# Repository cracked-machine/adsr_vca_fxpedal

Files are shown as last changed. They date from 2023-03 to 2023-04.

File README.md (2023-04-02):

# adsr_vca_fxpedal
MCU generated ADSR envelope into a LM13700 OTA VCA

## Block diagram

The audio input signal is amplitude-modulated with the ADSR waveform using the [LM13700](docs/datasheet/lm13700.pdf) in a voltage controlled amplifier (VCA) confguration.

ADSR waveform is generated via software running on a [microcontroller](docs/datasheet/stm32l432kb_datasheet.pdf) with built-in dual DAC. Two ADSR signals are generated: Inverted and Non-inverted.

ADSR generation is triggered by detecting the peak of the input signal or by manual push button. The latter can be used as a manual retrigger mechanism.

ADSR values - attack, decay, sustain and release - can be selected and then adjusted using the four potentiometers.  

An OLED display will show the current ADSR envelope shape as it is adjusted.

The raw ADSR envelope signal and VCA output are available as buffered output on 2.54mm connectors.



Both the inverted and non-inverted ADSR-modulated signals are mixed with the original "clean" audio input signal in the output stage. The mix of all three signals can be independently adjusted.

## Power Supply Scheme

This supports both guitar applications (9VDC) and modular synth (+/-12V) by switching the jumpers.

Note the 9VDC rail is split to +/-4.5VDC.



Implementation can be seen on the schematic page



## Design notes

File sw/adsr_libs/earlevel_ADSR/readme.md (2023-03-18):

https://www.earlevel.com/main/2013/06/03/envelope-generators-adsr-code/

### Compile

```
g++ -std=c++17 *.cpp -o adsr
```

### run

```
./adsr
```

### Example output

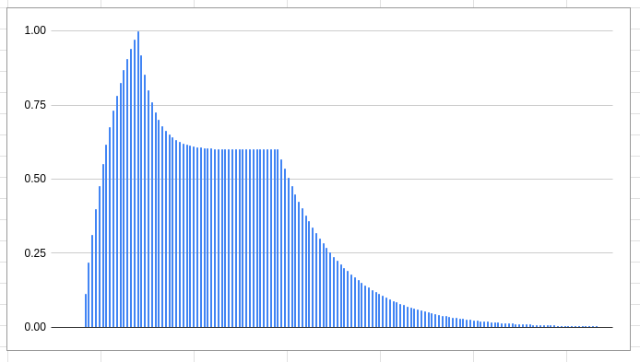
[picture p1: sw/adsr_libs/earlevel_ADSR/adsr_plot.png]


parameters:

```
sampleRate = 80
AttackRate = 0.1s
DecayRate = 0.25s
ReleaseRate = 1s
SustainLevel = 0.6
gate duration = 100ms
```

Raw data can be found in [data.txt](data.txt)

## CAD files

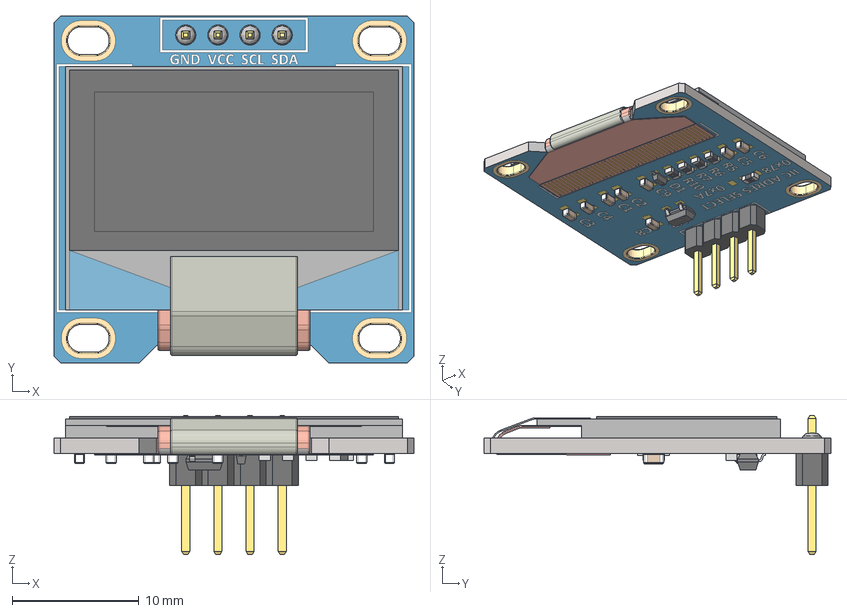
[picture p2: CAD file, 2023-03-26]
hw/3dmodels/Pantalla OLED 0.96'' 128x64.stp
28.4 x 27.4 x 11.0 mm
SOT-23_TOR
RES_CR16_MTK_1 x 4
RES_CR16_MTK
SOD323F_DIO

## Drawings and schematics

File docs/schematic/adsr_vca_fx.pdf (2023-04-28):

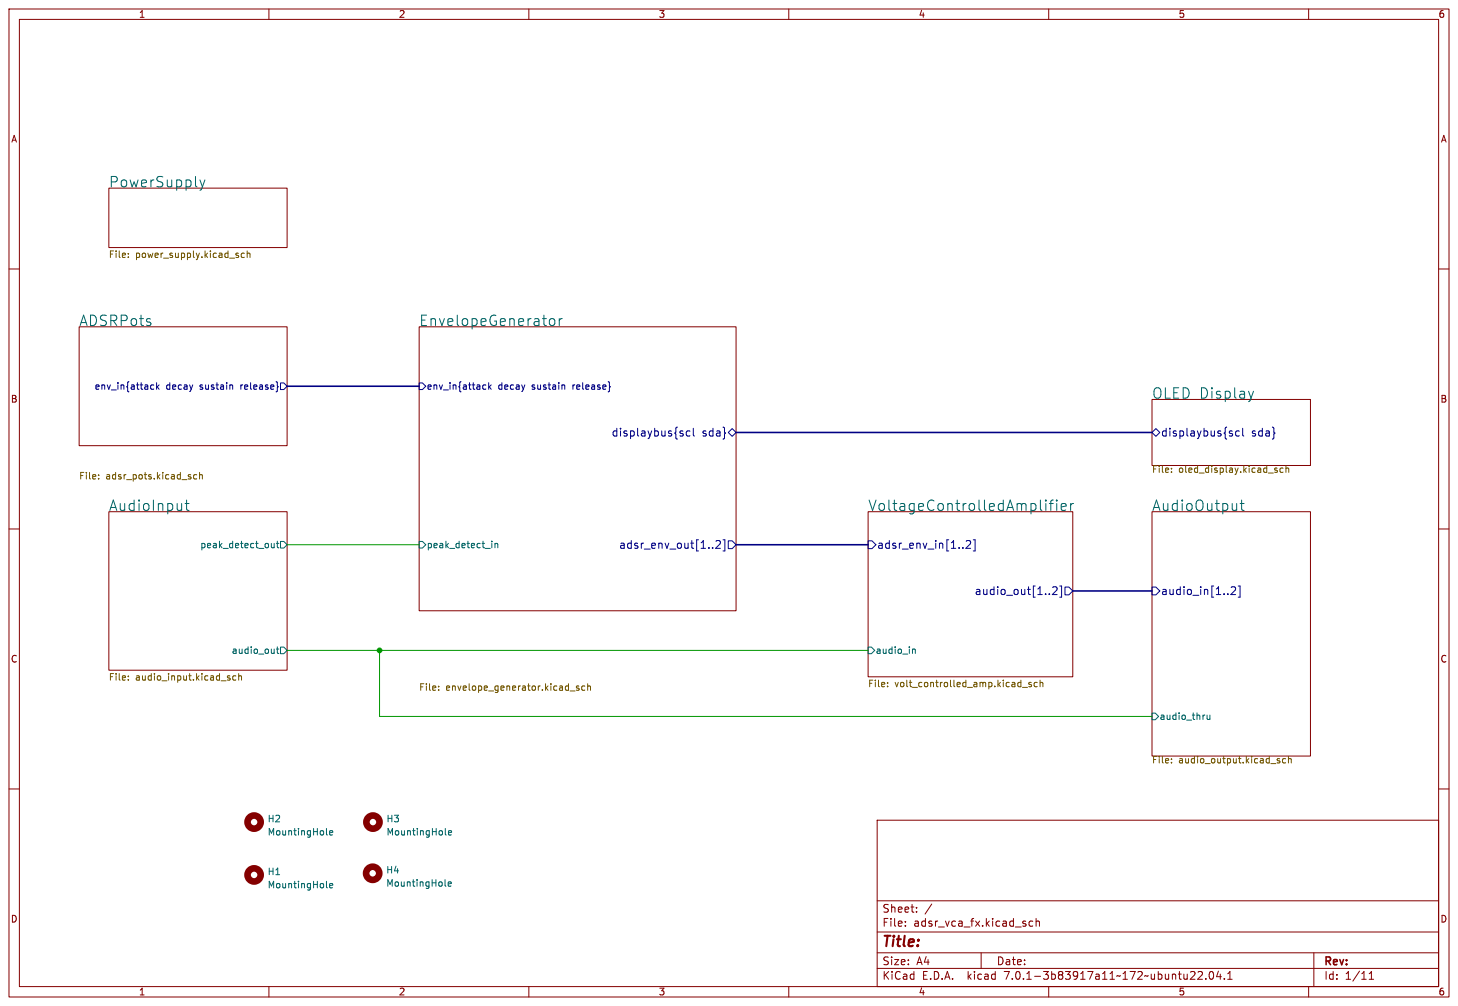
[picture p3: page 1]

EnvelopeGenerator File: envelope_generator.kicad_sch H3 MountingHole H4 MountingHole H1 MountingHole H2 MountingHole

Id: 1/11 Title: File: adsr_vca_fx.kicad_sch Sheet: /

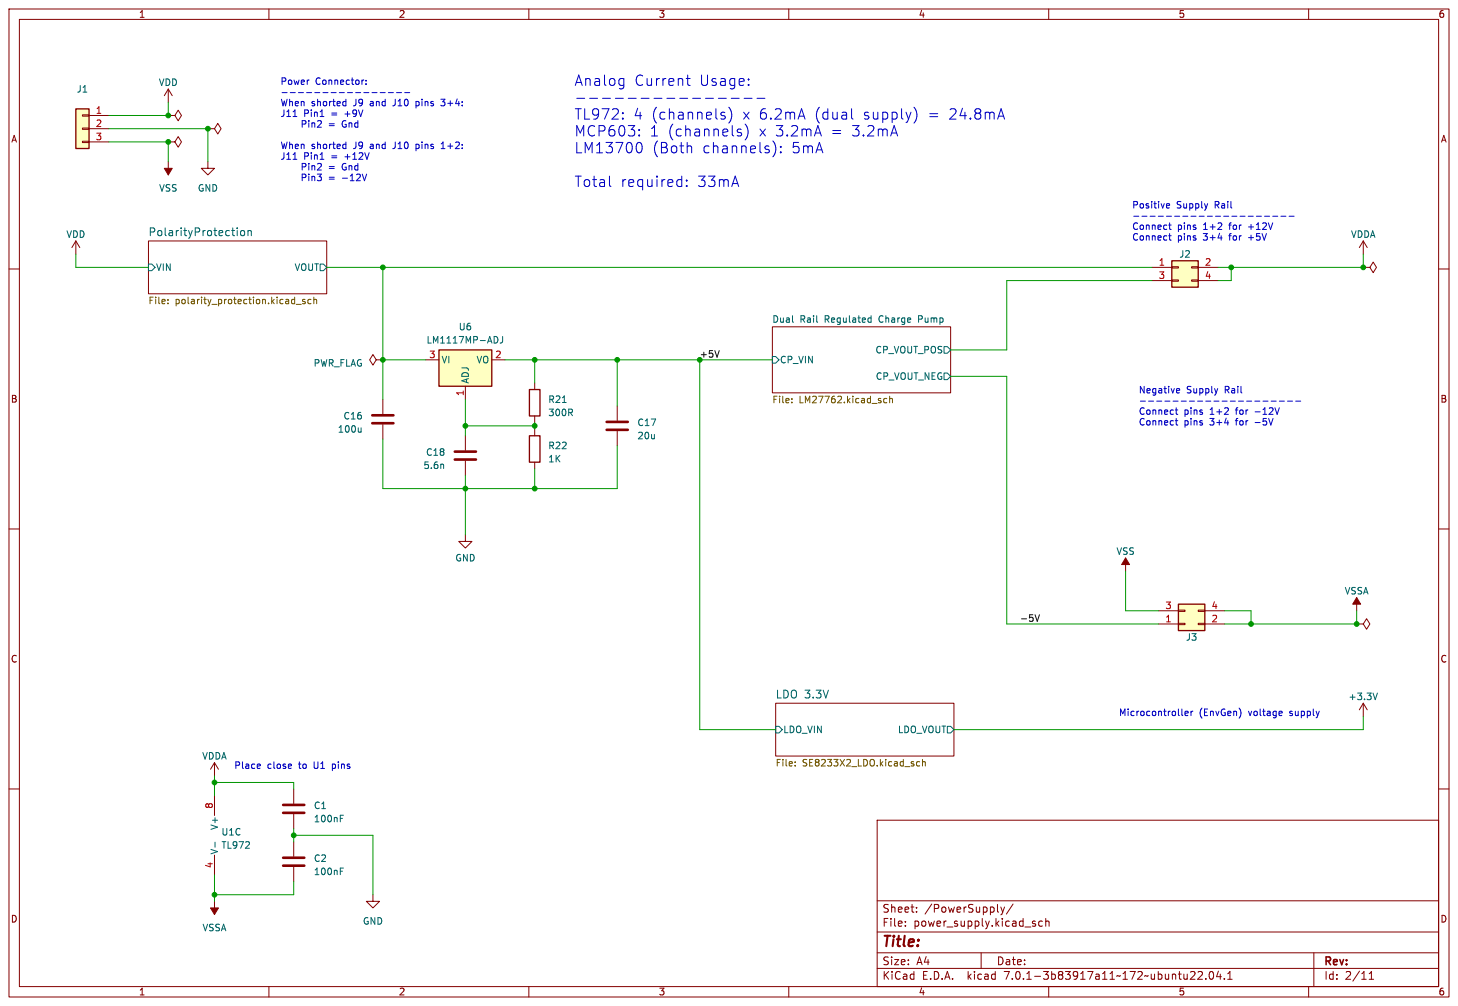
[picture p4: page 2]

Power Connector: ---------------- When shorted J9 and J10 pins 3+4: J11 Pin1 = +9V

Pin2 = Gnd When shorted J9 and J10 pins 1+2: J11 Pin1 = +12V

Dual Rail Regulated Charge Pump File: LM27762.kicad_sch

Negative Supply Rail -------------------- Connect pins 1+2 for -12V Connect pins 3+4 for -5V

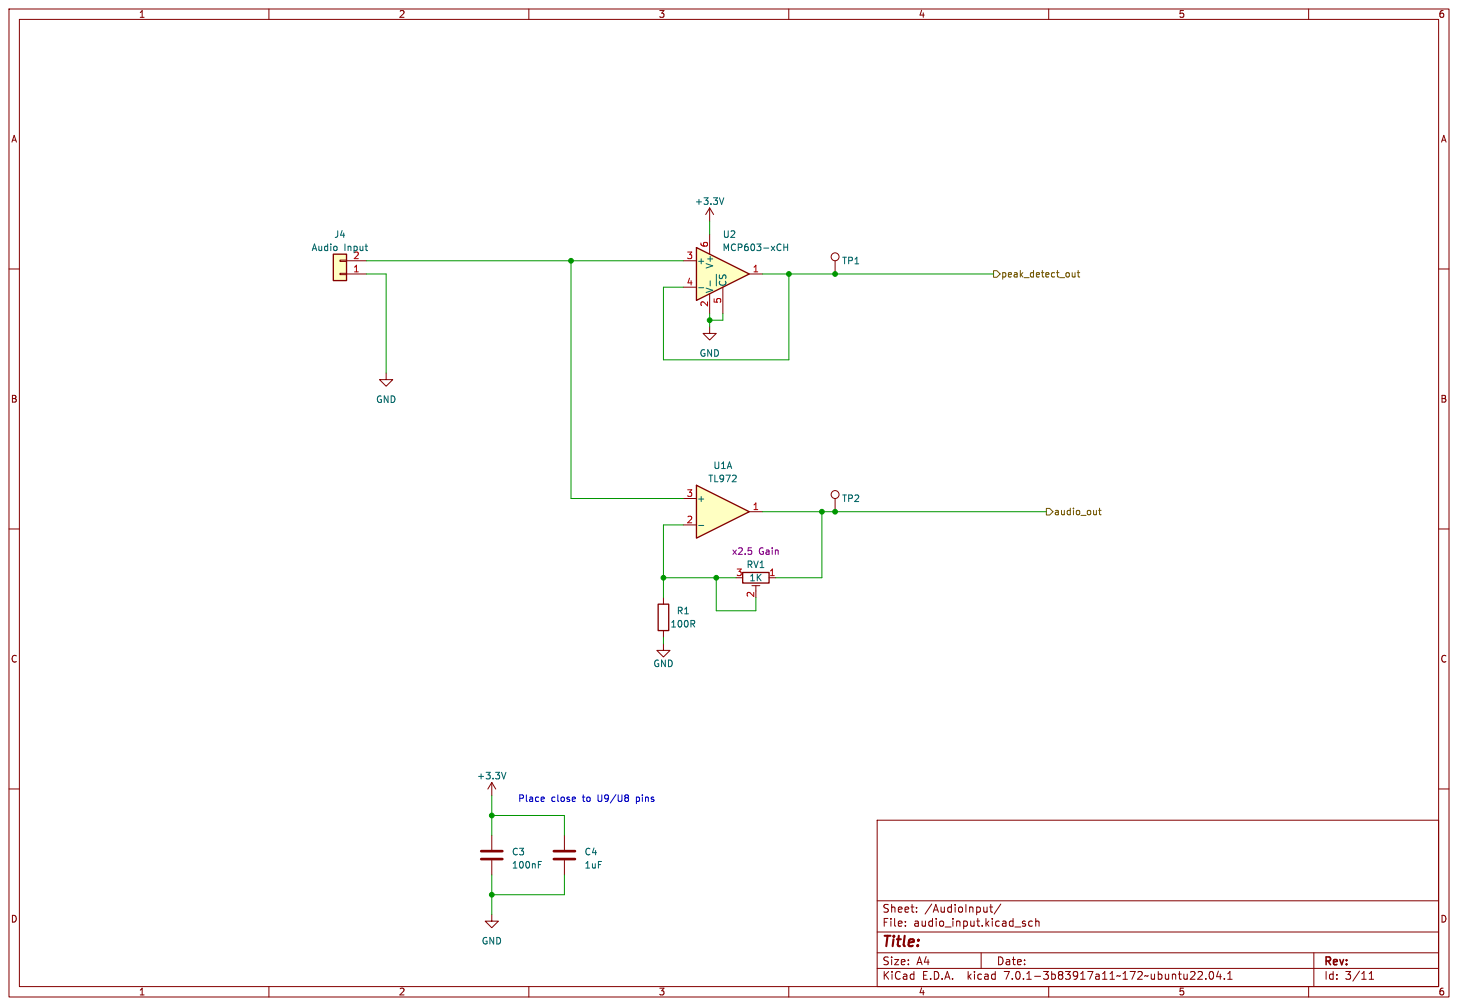
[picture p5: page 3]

Id: 3/11 Title: File: audio_input.kicad_sch Sheet: /AudioInput/ C4

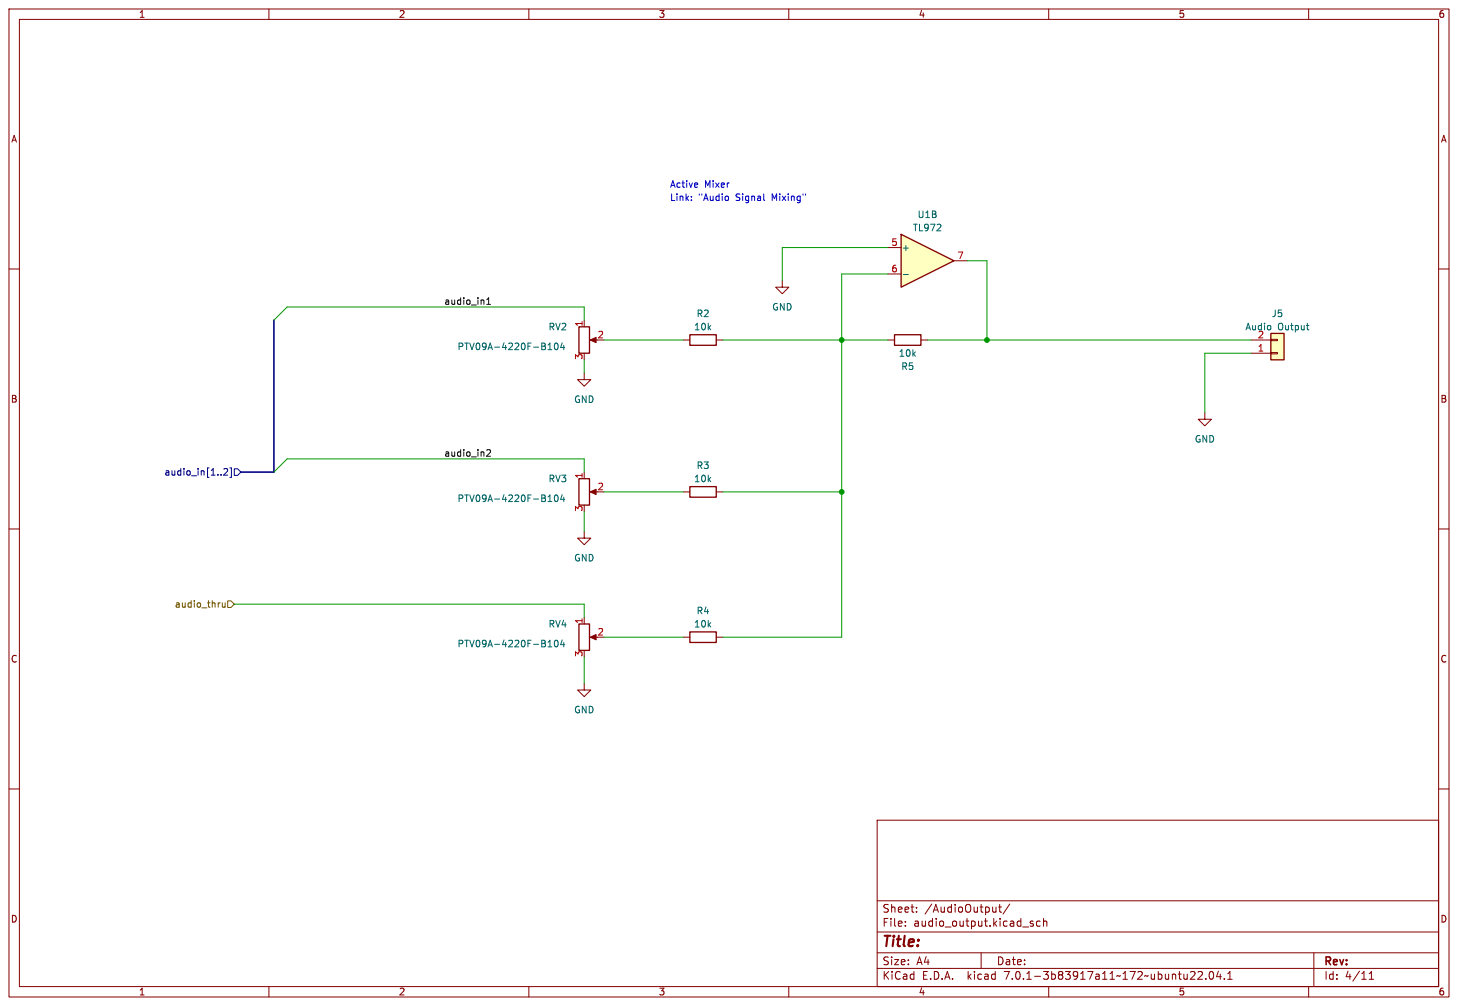
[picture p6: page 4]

Link: "Audio Signal Mixing" (https://sound-au.com/articles/audio-mixing.htm#s3) Active Mixer

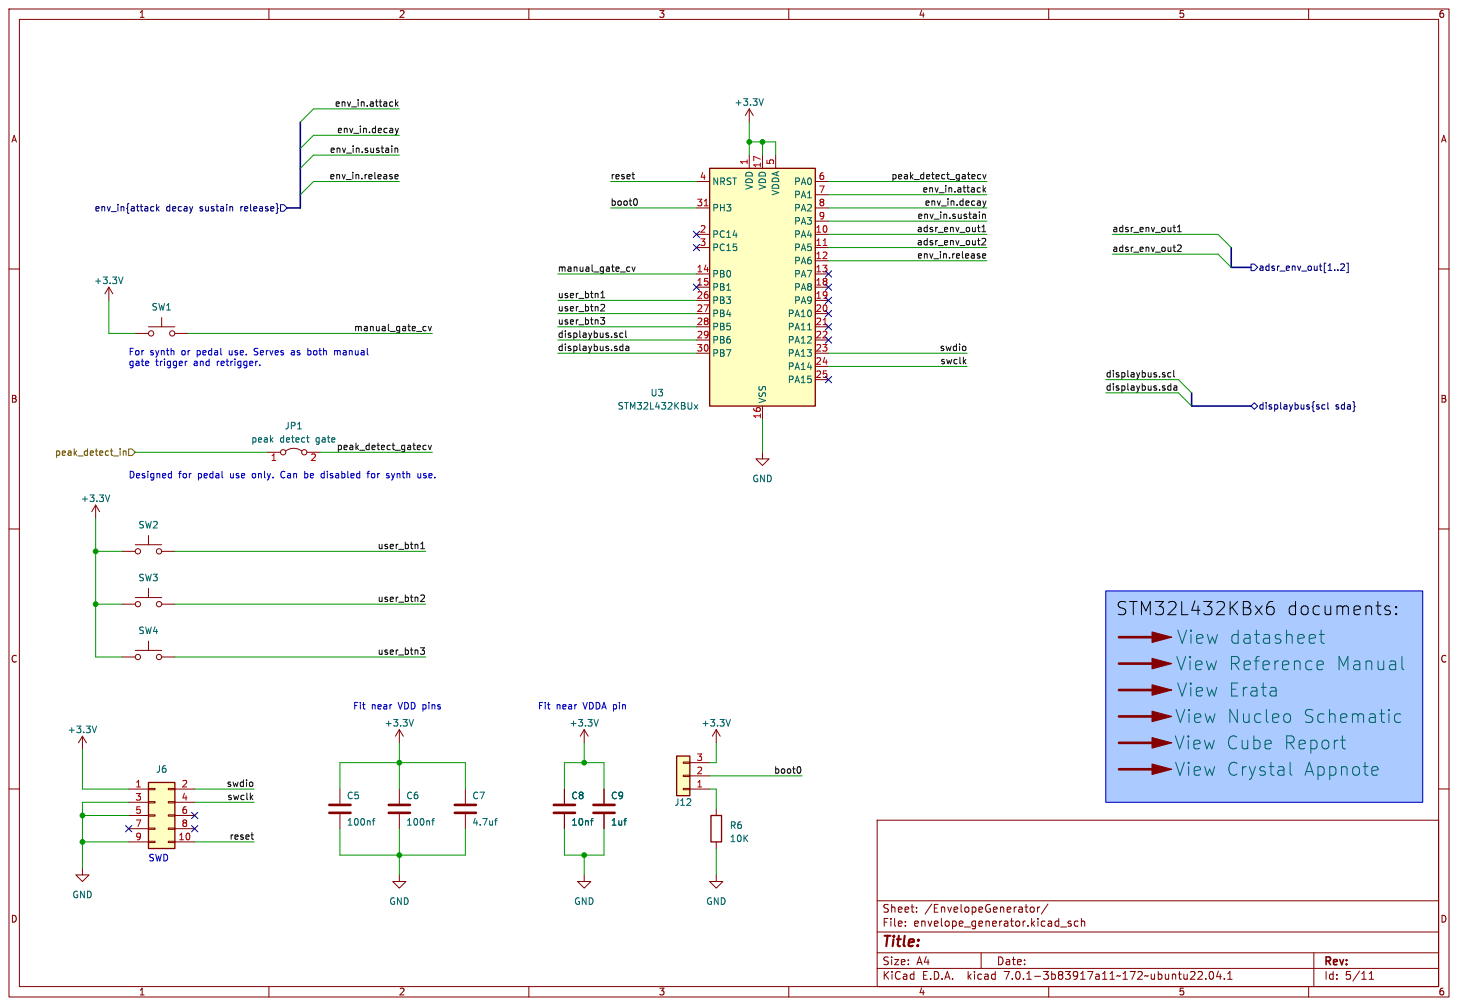
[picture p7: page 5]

1 PA4 10 PA5 11 PA6 12 PA7 13 PB0 14 PB1 15 VSS 16 VDD 17 PA8 18 PA9 19 PC14 2 PA10 20 PA11 21 PA12 22 PA13 23 PA14 24 PA15 25 PB3 26 PB4 27 PB5 28 PB6 29 PC15 3 PB7 30 PH3 31 NRST 4 VDDA

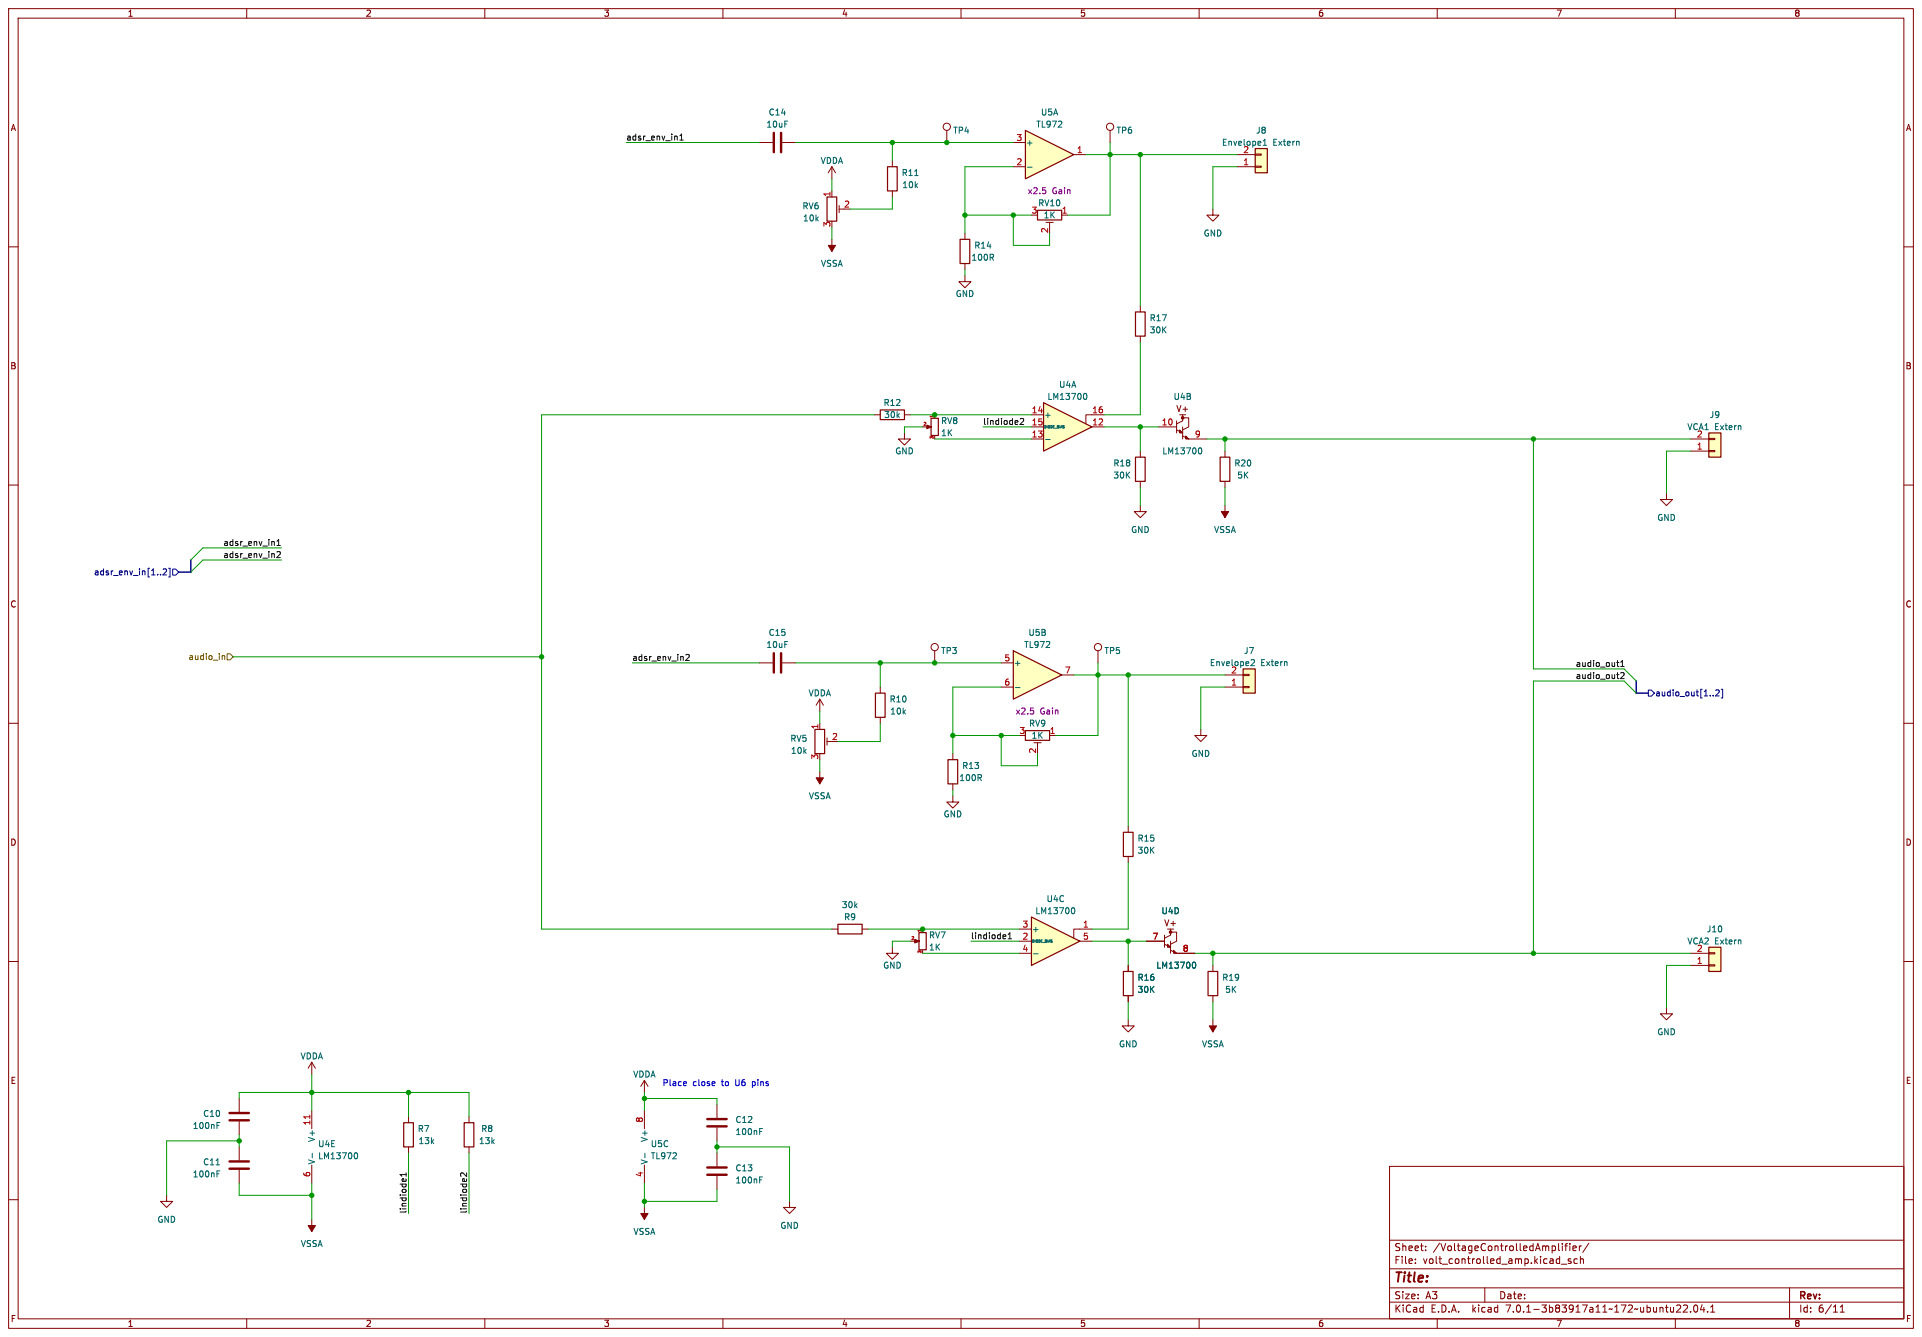
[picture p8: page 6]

Id: 6/11 Title: File: volt_controlled_amp.kicad_sch Sheet: /VoltageControlledAmplifier/

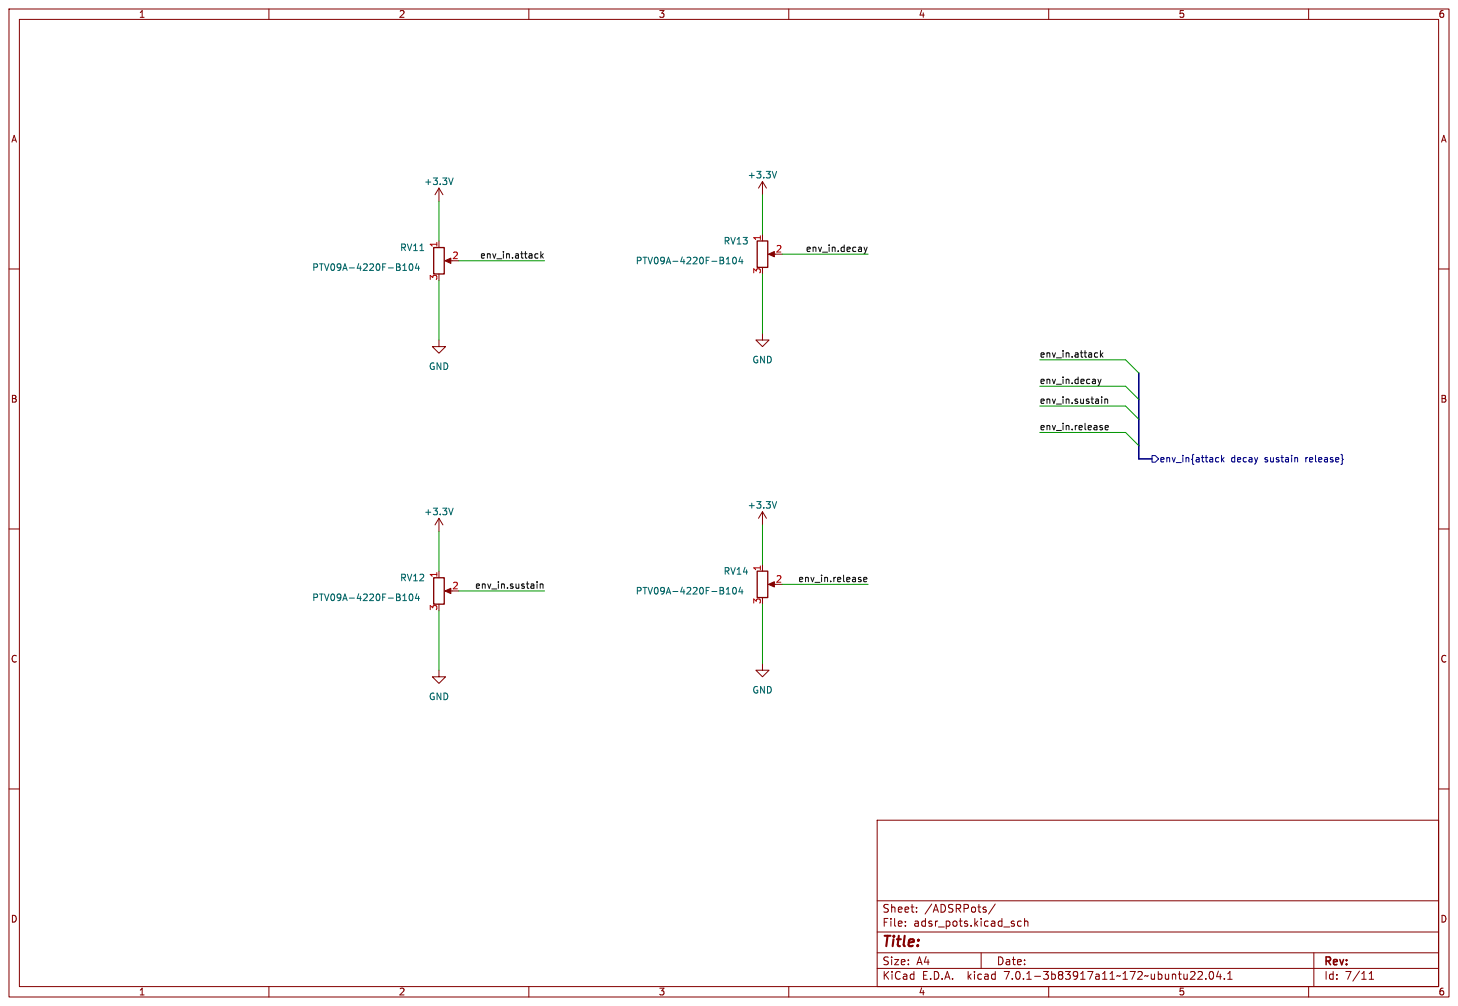
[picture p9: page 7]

Id: 7/11 Title: File: adsr_pots.kicad_sch Sheet: /ADSRPots/

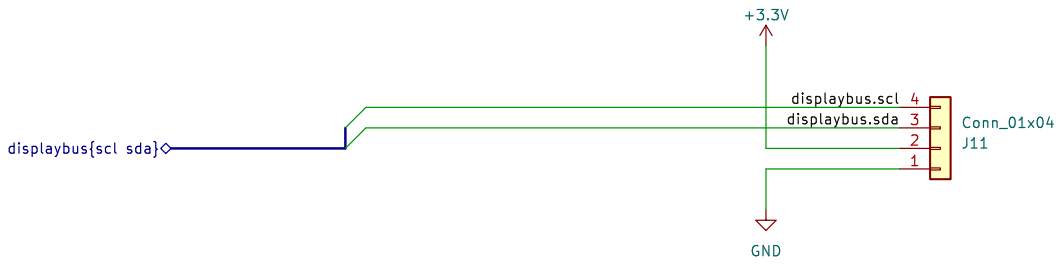
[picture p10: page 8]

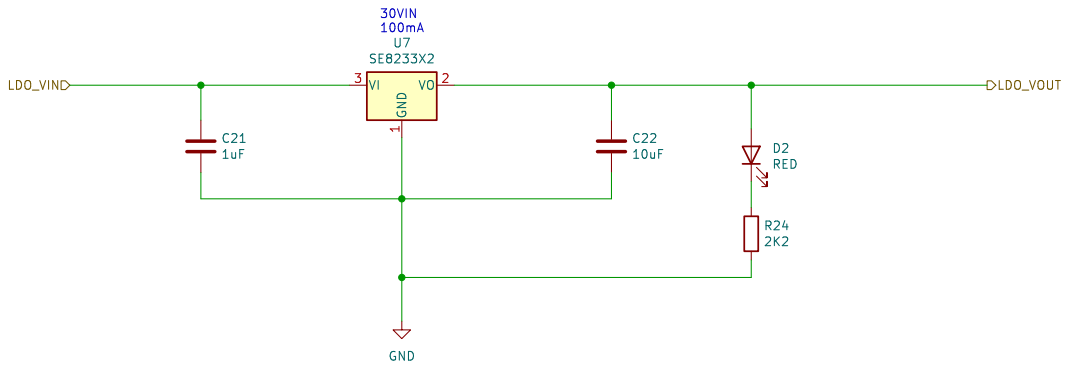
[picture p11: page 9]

Id: 11/11 Title: PSU - LDO 3.3V @ 100mA

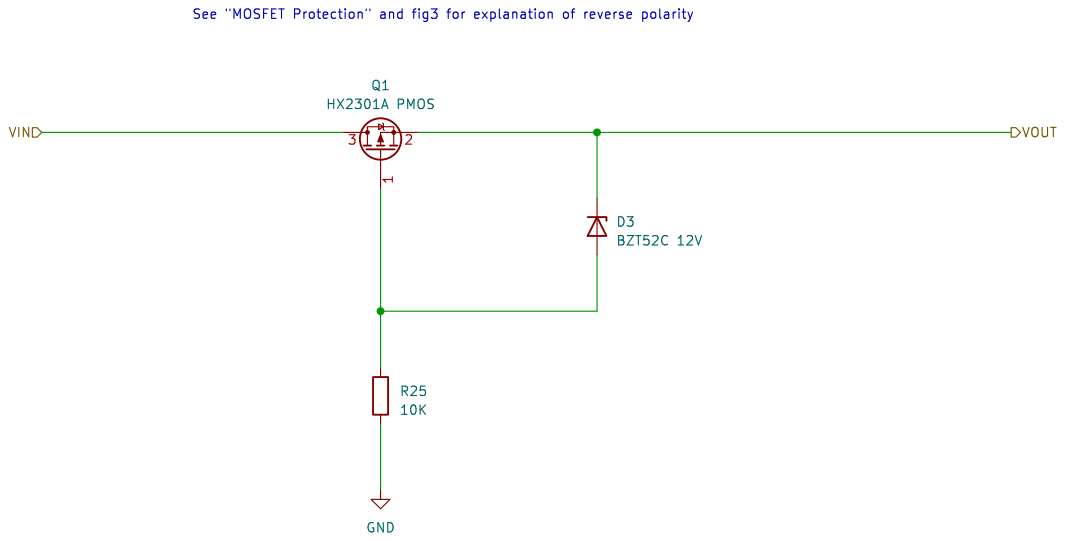
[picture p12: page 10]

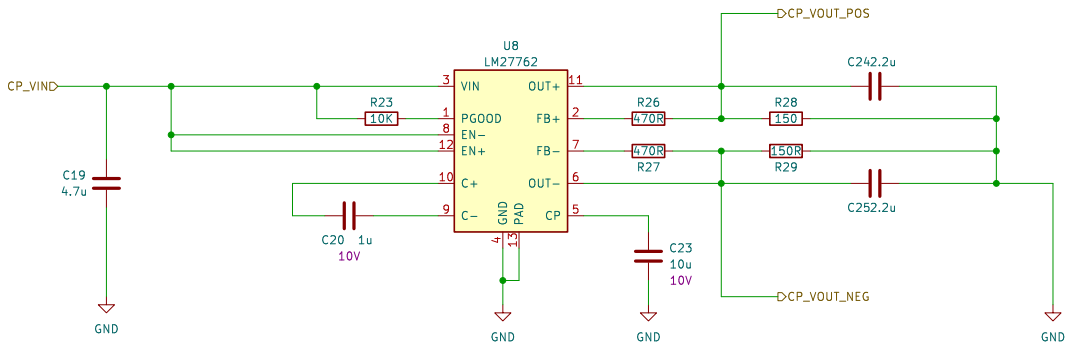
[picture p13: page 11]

4 CP 5 OUT- 6 FB- 7 EN- 8 C- 9 U8

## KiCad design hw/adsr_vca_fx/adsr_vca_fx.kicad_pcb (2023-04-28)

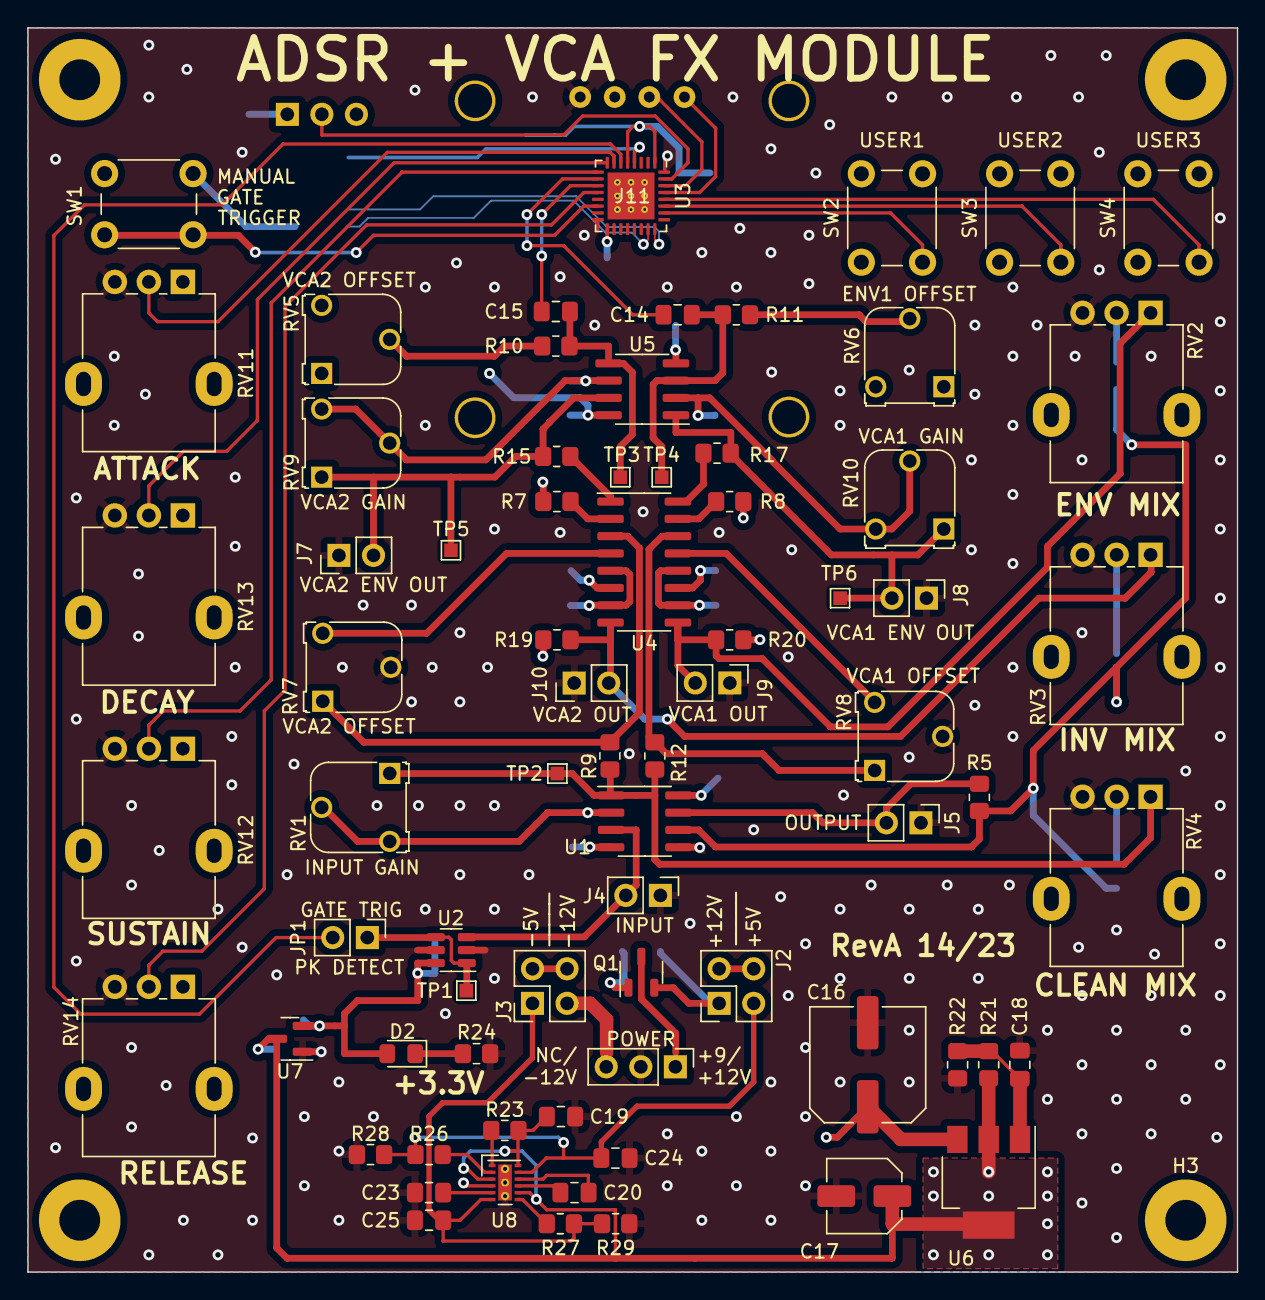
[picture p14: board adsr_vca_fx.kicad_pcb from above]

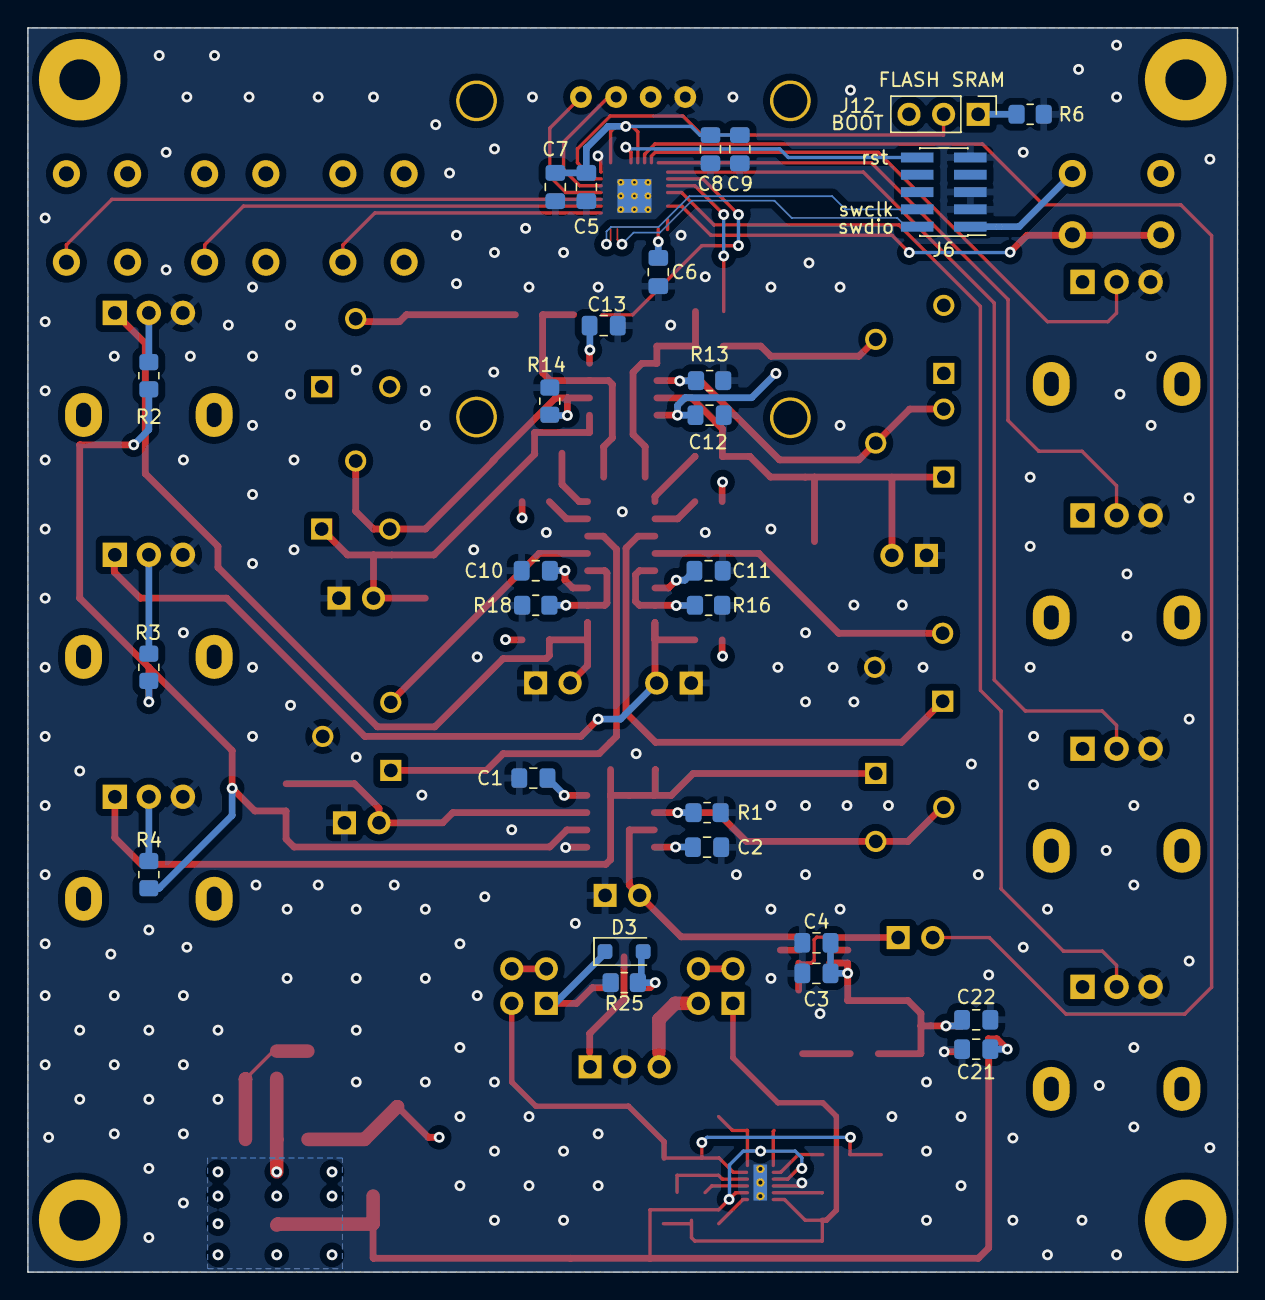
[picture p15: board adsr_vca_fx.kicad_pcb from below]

Board: 4 copper layers, 88.9 x 91.4 mm, 106 parts (28 on the bottom side), 66 nets.

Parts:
C1, C2, C3, C10, C11, C12, C13: 100nF; C_0805_2012Metric_Pad1.18x1.45mm_HandSolder
C4, C21: 1uF; C_0805_2012Metric_Pad1.18x1.45mm_HandSolder
C5, C6: 100nf; C_0805_2012Metric_Pad1.18x1.45mm_HandSolder
C7: 4.7uf; C_0805_2012Metric_Pad1.18x1.45mm_HandSolder
C8: 10nf; C_0805_2012Metric_Pad1.18x1.45mm_HandSolder
C9: 1uf; C_0805_2012Metric_Pad1.18x1.45mm_HandSolder
C14, C15, C22: 10uF; C_0805_2012Metric_Pad1.18x1.45mm_HandSolder
C16: 100u; C_Elec_8x5.4
C17: 20u; C_Elec_5x5.4
C18: 5.6n; C_0805_2012Metric_Pad1.18x1.45mm_HandSolder
C19: 4.7u; C_0805_2012Metric_Pad1.18x1.45mm_HandSolder
C20: 1u; C_0805_2012Metric_Pad1.18x1.45mm_HandSolder
C23: 10u; C_0805_2012Metric_Pad1.18x1.45mm_HandSolder
C24, C25: 2.2u; C_0805_2012Metric_Pad1.18x1.45mm_HandSolder
D2: RED; LED_0805_2012Metric_Pad1.15x1.40mm_HandSolder
D3: BZT52C 12V; D_SOD-123F
H1, H2, H3, H4: MountingHole; MountingHole_3mm_Pad
J1, J12: Conn_01x03; PinHeader_1x03_P2.54mm_Vertical
J2, J3: Conn_02x02_Odd_Even; PinHeader_2x02_P2.54mm_Vertical
J4: Audio Input; PinHeader_1x02_P2.54mm_Vertical
J5: Audio Output; PinHeader_1x02_P2.54mm_Vertical
J6: Conn_02x05_Odd_Even; PinHeader_2x05_P1.27mm_Vertical_SMD
J7: Envelope2 Extern; PinHeader_1x02_P2.54mm_Vertical
J8: Envelope1 Extern; PinHeader_1x02_P2.54mm_Vertical
J9: VCA1 Extern; PinHeader_1x02_P2.54mm_Vertical
J10: VCA2 Extern; PinHeader_1x02_P2.54mm_Vertical
J11: Conn_01x04; SSD1306_0.96_Oled_no_courtyard_no_silkscreen
JP1: peak detect gate; PinHeader_1x02_P2.54mm_Vertical
Q1: HX2301A PMOS; SOT-23-3
R1, R13, R14: 100R; R_0805_2012Metric_Pad1.20x1.40mm_HandSolder
R2, R3, R4, R5, R10, R11: 10k; R_0805_2012Metric_Pad1.20x1.40mm_HandSolder
R6, R23, R25: 10K; R_0805_2012Metric_Pad1.20x1.40mm_HandSolder
R7, R8: 13k; R_0805_2012Metric_Pad1.20x1.40mm_HandSolder
R9, R12: 30k; R_0805_2012Metric_Pad1.20x1.40mm_HandSolder
R15, R16, R17, R18: 30K; R_0805_2012Metric_Pad1.20x1.40mm_HandSolder
R19, R20: 5K; R_0805_2012Metric_Pad1.20x1.40mm_HandSolder
R21: 300R; R_0805_2012Metric_Pad1.20x1.40mm_HandSolder
R22: 1K; R_0805_2012Metric_Pad1.20x1.40mm_HandSolder
R24: 2K2; R_0805_2012Metric_Pad1.20x1.40mm_HandSolder
R26, R27: 470R; R_0805_2012Metric_Pad1.20x1.40mm_HandSolder
R28: 150; R_0805_2012Metric_Pad1.20x1.40mm_HandSolder
R29: 150R; R_0805_2012Metric_Pad1.20x1.40mm_HandSolder
RV1, RV7, RV8, RV9, RV10: 1K; Potentiometer_Runtron_RM-065_Vertical
RV2, RV3, RV4, RV11, RV12, RV13, RV14: PTV09A-4220F-B104; Potentiometer_Alpha_RD901F-40-00D_Single_Vertical
RV5, RV6: 10k; Potentiometer_Runtron_RM-065_Vertical
SW1, SW2, SW3, SW4: SW_Push; SW_PUSH_6mm
TP1, TP2, TP3, TP4, TP5, TP6: TestPoint; TestPoint_Pad_1.0x1.0mm
U1, U5: TL972; SOIC-8_3.9x4.9mm_P1.27mm
U2: MCP603-xCH; SOT-23-6
U3: STM32L432KBUx; QFN-32-1EP_5x5mm_P0.5mm_EP3.45x3.45mm_ThermalVias
U4: LM13700; SOIC-16_3.9x9.9mm_P1.27mm
U6: LM1117MP-ADJ; SOT-223-3_TabPin2
U7: SE8233X2; SOT-23
U8: LM27762; WSON-12-1EP_3x2mm_P0.5mm_EP1x2.65_ThermalVias

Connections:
+3.3V: C3.1, C4.1, C5.1, C6.1, C7.1, C8.1, C9.1, C22.1, D2.2 (A), J6.1, J11.2, J12.3, RV11.1, RV12.1, RV13.1, RV14.1, SW1.1, SW2.1, SW3.1, SW4.1, U2.6 (V+), U3.1 (VDD), U3.5 (VDDA), U3.17 (VDD), U7.2 (VO)
/ADSRPots/env_in.attack: RV11.2, U3.7 (PA1)
/ADSRPots/env_in.decay: RV13.2, U3.8 (PA2)
/ADSRPots/env_in.release: RV14.2, U3.12 (PA6)
/ADSRPots/env_in.sustain: RV12.2, U3.9 (PA3)
/AudioInput/audio_out: R9.1, R12.1, RV1.1, RV4.1, TP2.1, U1.1
/AudioInput/peak_detect_out: JP1.1 (A), TP1.1, U2.1, U2.4 (-)
/AudioOutput/audio_in1: J9.2, R20.2, RV2.1, U4.9
/AudioOutput/audio_in2: J10.2, R19.2, RV3.1, U4.8
/EnvelopeGenerator/adsr_env_out1: C14.1, U3.10 (PA4)
/EnvelopeGenerator/adsr_env_out2: C15.1, U3.11 (PA5)
/EnvelopeGenerator/boot0: J12.2, U3.31 (PH3)
/EnvelopeGenerator/displaybus.scl: J11.4, U3.29 (PB6)
/EnvelopeGenerator/displaybus.sda: J11.3, U3.30 (PB7)
/EnvelopeGenerator/manual_gate_cv: SW1.2, U3.14 (PB0)
/EnvelopeGenerator/peak_detect_gatecv: JP1.2 (B), U3.6 (PA0)
/EnvelopeGenerator/reset: J6.10, U3.4 (NRST)
/EnvelopeGenerator/swclk: J6.4, U3.24 (PA14)
/EnvelopeGenerator/swdio: J6.2, U3.23 (PA13)
/EnvelopeGenerator/user_btn1: SW2.2, U3.26 (PB3)
/EnvelopeGenerator/user_btn2: SW3.2, U3.27 (PB4)
/EnvelopeGenerator/user_btn3: SW4.2, U3.28 (PB5)
/PowerSupply/+5V: C17.1, C19.1, C21.1, R21.1, R23.1, U6.2 (VO), U7.3 (VI), U8.3 (VIN), U8.8 (EN-), U8.12 (EN+)
/PowerSupply/-5V: C25.1, J3.1, R27.2, R29.1, U8.6 (OUT-)
/PowerSupply/Dual Rail Regulated Charge Pump/CP_VOUT_POS: C24.1, J2.3, R26.2, R28.1, U8.11 (OUT+)
/PowerSupply/PolarityProtection/VOUT: C16.1, D3.1 (K), J2.1, Q1.2 (S), U6.3 (VI)
/VoltageControlledAmplifier/lindiode1: R7.1, U4.2 (DIODE_BIAS)
/VoltageControlledAmplifier/lindiode2: R8.1, U4.15 (DIODE_BIAS)
GND: C1.2, C2.1, C3.2, C4.2, C5.2, C6.2, C7.2, C8.2, C9.2, C10.2, C11.1, C12.2, C13.1, C16.2, C17.2, C18.2, C19.2, C21.2, C22.2, C23.2, C24.2, C25.2, J1.2, J4.1, J5.1, J6.3, J6.5, J6.9, J7.1, J8.1, J9.1, J10.1, J11.1, R1.1, R6.2, R13.1, R14.1, R16.1, R18.1, R22.2, R24.2, R25.2, R28.2, R29.2, RV2.3, RV3.3, RV4.3, RV7.2, RV8.2, RV11.3, RV12.3, RV13.3, RV14.3, U1.5 (+), U2.2 (V-), U2.5 (~CS), U3.16 (VSS), U3.32 (VSS), U3.33 (VSS), U7.1 (GND), U8.4 (GND), U8.13 (PAD)
unnamed: D2.1 (K), R24.1
unnamed: D3.2 (A), Q1.1 (G), R25.1
unnamed: J4.2, U1.3 (+), U2.3 (+)
unnamed: J5.2, R5.2, U1.7
unnamed: J7.2, R15.2, RV9.1, TP5.1, U5.7
unnamed: J8.2, R17.2, RV10.1, TP6.1, U5.1
unnamed: J12.1, R6.1
unnamed: R2.1, RV2.2
unnamed: R3.1, RV3.2
unnamed: R4.1, RV4.2
unnamed: R10.1, RV5.2
unnamed: R11.1, RV6.2
unnamed: R15.1, U4.1
unnamed: R16.2, U4.5, U4.7
unnamed: R17.1, U4.16
unnamed: R18.2, U4.10, U4.12
unnamed: R1.2, RV1.2, RV1.3, U1.2 (-)
unnamed: R2.2, R3.2, R4.2, R5.1, U1.6 (-)
unnamed: R12.2, RV8.1, U4.14 (+)
unnamed: RV8.3, U4.13 (-)
unnamed: R9.2, RV7.1, U4.3 (+)
unnamed: RV7.3, U4.4 (-)
unnamed: C14.2, R11.2, TP4.1, U5.3 (+)
unnamed: R14.2, RV10.2, RV10.3, U5.2 (-)
unnamed: C15.2, R10.2, TP3.1, U5.5 (+)
unnamed: R13.2, RV9.2, RV9.3, U5.6 (-)
unnamed: C18.1, R21.2, R22.1, U6.1 (ADJ)
unnamed: C20.2, U8.10 (C+)
unnamed: C20.1, U8.9 (C-)
unnamed: C23.1, U8.5 (CP)
unnamed: R26.1, U8.2 (FB+)
unnamed: R27.1, U8.7 (FB-)
unnamed: R23.2, U8.1 (PGOOD)
VDD: J1.1, Q1.3 (D)
VDDA: C1.1, C10.1, C12.1, J2.2, J2.4, R7.2, R8.2, RV5.1, RV6.1, U1.8 (V+), U4.11 (V+), U5.8 (V+)
VSS: J1.3, J3.3
VSSA: C2.2, C11.2, C13.2, J3.2, J3.4, R19.1, R20.1, RV5.3, RV6.3, U1.4 (V-), U4.6 (V-), U5.4 (V-)

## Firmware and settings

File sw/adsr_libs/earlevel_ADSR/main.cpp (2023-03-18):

#include "ADSR.h"
#include <iostream>
#include <thread>
#include <chrono>
#include <fstream>

using namespace std::chrono_literals;


// create ADSR env
ADSR *env = new ADSR();

// normally this would be called everytime the ADC DMA new data flag was set
// but for simulation purpose we run it in a loop
void adc_dma_callback(int samplerate)
{
    std::ofstream f_data("data.txt");

    std::cout << "Starting gate thread\n";
    for(int i = 0; i < samplerate; i++)
    {
        std::this_thread::sleep_for(2ms);
        f_data << env->process() << std::endl;
    }
}

int main()
{
    
    float sampleRate = 160;

    // initialize settings
    env->setAttackRate(.1 * sampleRate);  // .1 second
    env->setDecayRate(.25 * sampleRate);
    env->setReleaseRate(1 * sampleRate);
    env->setSustainLevel(.6);
    
    std::thread t1(adc_dma_callback, sampleRate);

    std::this_thread::sleep_for(20ms);
    std::cout << "gate on\n";
    env->gate(true);

    std::this_thread::sleep_for(120ms);
    std::cout << "gate off\n";
    env->gate(false);


    std::this_thread::sleep_for(2000ms);    

    t1.join();
    
    return 0;
}

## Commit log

2023-03-18 first schema draft
    [SE8233X2_LDO.kicad_sch, TPS563200_BUCK.kicad_sch, TPS60403_NEGVOLT.kicad_sch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]
2023-03-19 modified design into normal/inverted envlope
    [TPS60403_Parallel_NEGVOLT.kicad_sch, adsr_vca_fx.kicad_sch, audio_input.kicad_sch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]
2023-03-21 renamed sheet
    [TPS60403_NEGVOLT.kicad_sch, TPS60403_Parallel_NEGVOLT.kicad_sch, adsr_pots.kicad_sch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]
2023-03-21 added OLED footprint
    [oled_display.kicad_sch]
2023-03-21 updated text labels
    [audio_input.kicad_sch, audio_output.kicad_sch, volt_controlled_amp.kicad_sch]
2023-03-25 first draft layout
    [SE8233X2_LDO.kicad_sch, TPS563200_BUCK.kicad_sch, TPS60403_Parallel_NEGVOLT.kicad_sch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]
2023-03-26 tidied up layout
    [adsr_vca_fx.kicad_pcb, envelope_generator.kicad_sch]
2023-03-26 updated layout
    [Pantalla OLED 0.96'' 128x64.stp, adsr_vca_fx.kicad_pcb, envelope_generator.kicad_sch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]
2023-04-03 completed layout
    [SE8233X2_LDO.kicad_sch, TPS563200_BUCK.kicad_sch, TPS60403_Parallel_NEGVOLT.kicad_sch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]
2023-04-28 RevB; simplified power supply
    [LM27762.kicad_sch, adsr_vca_fx.kicad_pcb, power_supply.kicad_sch]
